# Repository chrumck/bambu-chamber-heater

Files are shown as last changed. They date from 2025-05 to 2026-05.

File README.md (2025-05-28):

# Bambu Lab X1 Chamber Heater Controller

## Description

Code for Bambu Lab X1 Carbon chamber heater controller.
It controls the chamber heater fan, heater core, the chamber light, and the external enclosure fan.
The input are two temperature sensors, the chamber temp sensor and the heater core temp sensor.

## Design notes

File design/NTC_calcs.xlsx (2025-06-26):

Arduino Resolution: | 4.9 | mV | 20.46
Sensors
Vref | 3.3 | V | ATmega32U4
Rref | 4700 | Ohm
Rsensor | 25000 | Ohm
Vout | 2.778 | V
I | 0.11 | mA
I | 0.00011 | A
Rsensor | 25000 | Ohm
 | Rref | Rmin | Rmax | Imin (mA) | Imax (mA) | vmin (V) | vmax (V) | vmin (mV) | vmax (mV) | Pmax (W) | Rmin | Rmax
Temp | 4700 | 120 | 160000 | 0.68 | 0.02 | 0.082 | 3.206 | 82.15767635 | 3205.82878 | 6.612021858e-05 | 4820 | 164700
 | degC | R | I (mA) | I (uA) | U (V)
 | 0 | 327240 | 0.010 | 9.941555703 | 3.253
 | 10 | 199990 | 0.016 | 16.1219405 | 3.224
 | 25 | 100000 | 0.032 | 31.51862464 | 3.152
 | 40 | 53500 | 0.057 | 56.70103093 | 3.034
 | 50 | 35899 | 0.081 | 81.28279022 | 2.918
 | 60 | 25000 | 0.111 | 111.1111111 | 2.778
 | 80 | 12540 | 0.191 | 191.4153132 | 2.400
 | 100 | 6710 | 0.289 | 289.2199825 | 1.941
 | 125 | 3340 | 0.410 | 410.4477612 | 1.371
 | 200 | 582 | 0.625 | 624.7633472 | 0.364

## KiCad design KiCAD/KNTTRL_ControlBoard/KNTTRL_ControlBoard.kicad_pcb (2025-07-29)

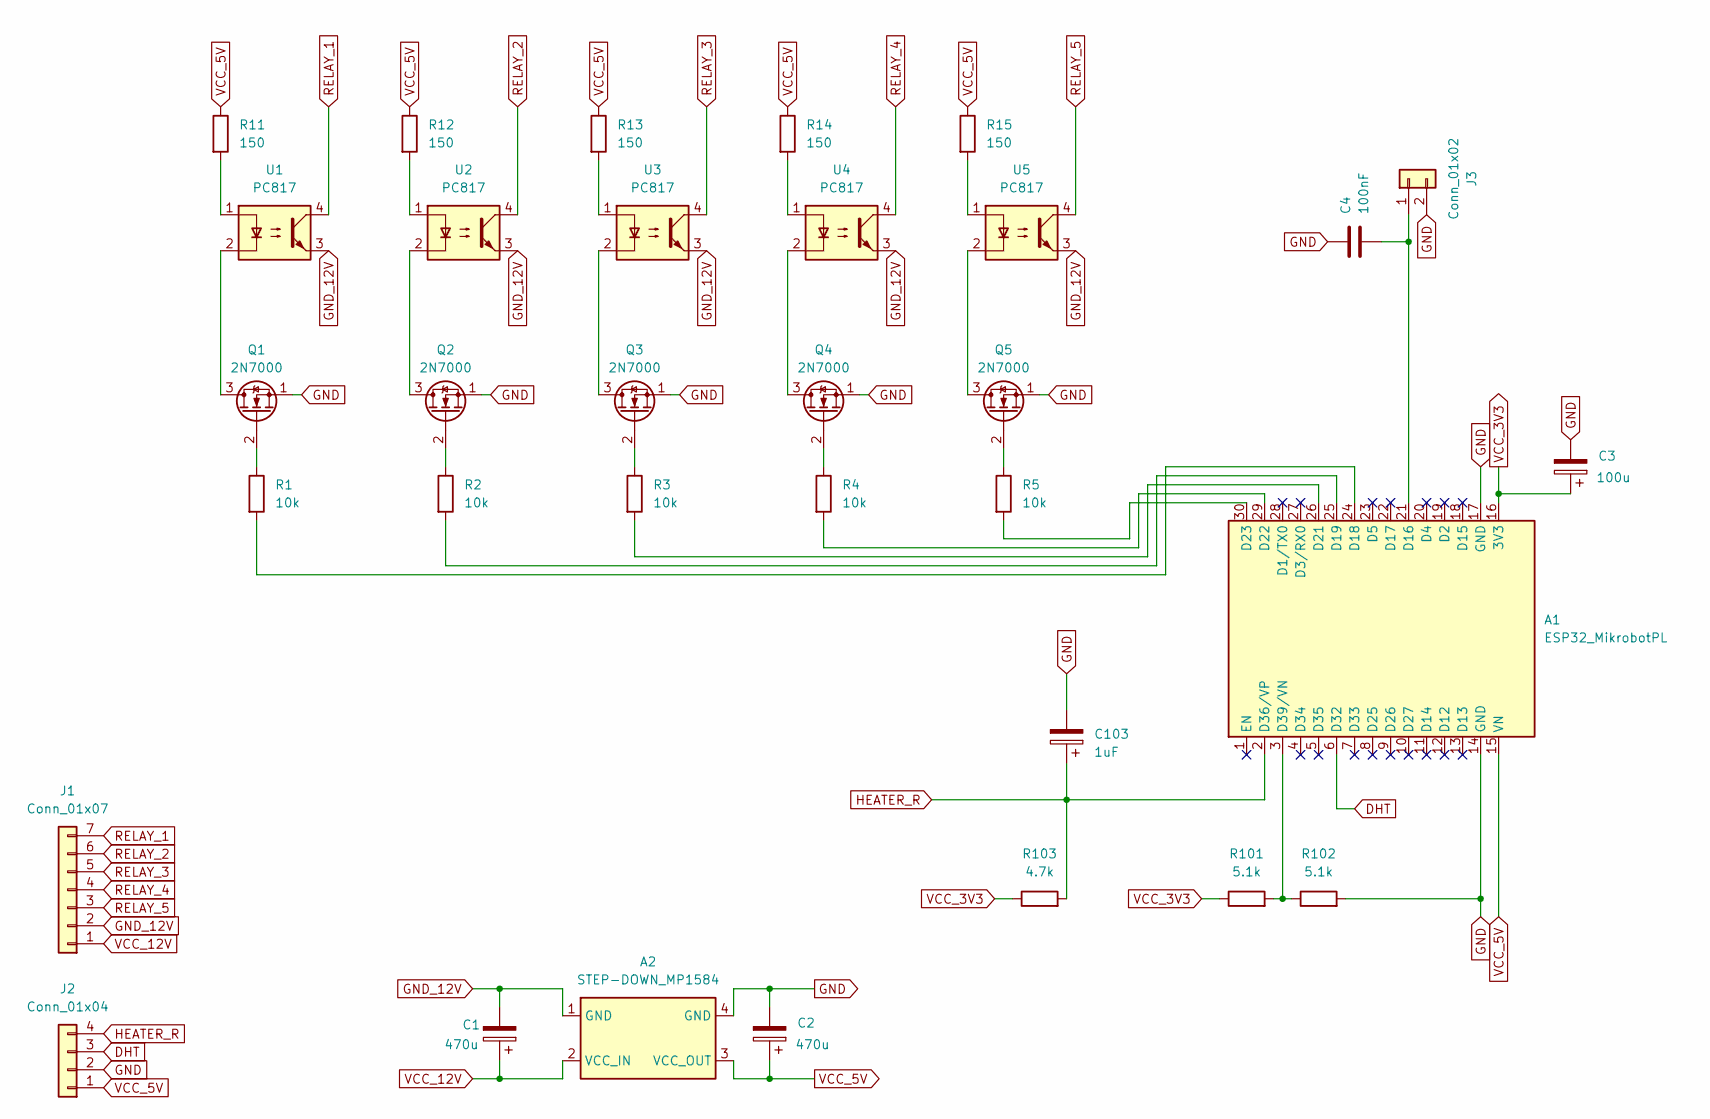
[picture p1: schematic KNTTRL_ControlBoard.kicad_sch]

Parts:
A1: ESP32_MikrobotPL
A2: STEP-DOWN_MP1584
C1, C2: 470u; CP_Radial_D5.0mm_P2.50mm
C3: 100u; CP_Radial_D5.0mm_P2.50mm
C4: 100nF; C_Disc_D5.0mm_W2.5mm_P2.50mm
C103: 1uF; CP_Radial_D5.0mm_P2.50mm
J1: Conn_01x07; PinHeader_1x07_P2.54mm_Vertical
J2: Conn_01x04; PinHeader_1x04_P2.54mm_Vertical
J3: Conn_01x02; PinHeader_1x02_P2.54mm_Vertical
Q1, Q2, Q3, Q4, Q5: 2N7000; TO-92_Inline_Wide
R1, R2, R3, R4, R5: 10k; R_Axial_DIN0207_L6.3mm_D2.5mm_P7.62mm_Horizontal
R11, R12, R13, R14, R15: 150; R_Axial_DIN0309_L9.0mm_D3.2mm_P2.54mm_Vertical
R101, R102: 5.1k; R_Axial_DIN0207_L6.3mm_D2.5mm_P7.62mm_Horizontal
R103: 4.7k; R_Axial_DIN0207_L6.3mm_D2.5mm_P7.62mm_Horizontal
U1, U2, U3, U4, U5: PC817; DIP-4_W7.62mm

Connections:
DHT: A1.6 (D32), J2.3
GND: A1.14 (GND), A1.17 (GND), A2.4 (GND), C2.2, C3.2, C4.1, C103.2, J2.2, J3.2, Q1.1 (S), Q2.1 (S), Q3.1 (S), Q4.1 (S), Q5.1 (S), R102.2
GND_12V: A2.1 (GND), C1.2, J1.2 (GND_12V), U1.3, U2.3, U3.3, U4.3, U5.3
HEATER_R: A1.2 (D36/VP), C103.1, J2.4, R103.2
unnamed: A1.21 (D16), C4.2, J3.1
unnamed: A1.24 (D18), R1.2
unnamed: A1.25 (D19), R2.2
unnamed: A1.26 (D21), R3.2
unnamed: A1.29 (D22), R4.2
unnamed: A1.30 (D23), R5.2
unnamed: A1.3 (D39/VN), R101.2, R102.1
unnamed: Q1.3 (D), U1.2
unnamed: Q1.2 (G), R1.1
unnamed: Q2.3 (D), U2.2
unnamed: Q2.2 (G), R2.1
unnamed: Q3.3 (D), U3.2
unnamed: Q3.2 (G), R3.1
unnamed: Q4.3 (D), U4.2
unnamed: Q4.2 (G), R4.1
unnamed: Q5.3 (D), U5.2
unnamed: Q5.2 (G), R5.1
unnamed: R11.2, U1.1
unnamed: R12.2, U2.1
unnamed: R13.2, U3.1
unnamed: R14.2, U4.1
unnamed: R15.2, U5.1
RELAY_1: J1.7, U1.4
RELAY_2: J1.6, U2.4
RELAY_3: J1.5, U3.4
RELAY_4: J1.4, U4.4
RELAY_5: J1.3, U5.4
VCC_3V3: A1.16 (3V3), C3.1, R101.1, R103.1
VCC_5V: A1.15 (VN), A2.3 (VCC_OUT), C2.1, J2.1, R11.1, R12.1, R13.1, R14.1, R15.1
VCC_12V: A2.2 (VCC_IN), C1.1, J1.1 (VCC_12V)

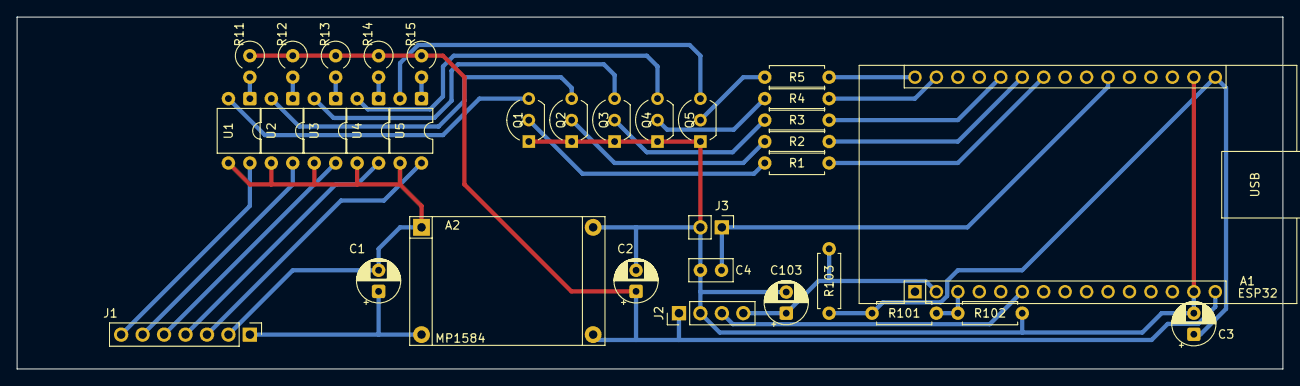
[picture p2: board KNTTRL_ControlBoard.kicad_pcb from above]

Board: 2 copper layers, 149.9 x 41.7 mm, 33 parts (0 on the bottom side), 34 nets.

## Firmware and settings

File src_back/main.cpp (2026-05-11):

#include "./main.hpp"

Preferences prefs;
AsyncWebServer server(80);
AsyncWebSocket ws("/ws");

u32_t lightButtonPressTime = 0;
volatile bool loopRunRequested = false;

// All temperatures in DegC if otherwise not specified
float chamberTemp = TEMP_DEFAULT;
u8_t tempSet = DEFAULT_TEMP_SET;
u8_t dhtFailCount = 0;

float vRef = 0.0;
float heaterV = 0.0;
float heaterR = 0.0;
float heaterLastDutyCycle = 0.0;

// All times are in milliseconds from last boot if otherwise not specified
u32_t operationMaxTime = 0;

bool heaterFanSet = false;
bool doorFanSet = false;
bool auxFanSet = false;

DHTNEW dht(DHT_PIN);

void setup() {
  Serial.setRxBufferSize(SERIAL_BUFFER_SIZE);
  Serial.begin(SERIAL_BAUD_RATE);

  pinMode(LIGHT_PIN, OUTPUT);
  switchRelayOn(LIGHT_PIN);  // Light on by default
  pinMode(AUX_FAN_PIN, OUTPUT);
  switchRelayOff(AUX_FAN_PIN);
  pinMode(DOOR_FAN_PIN, OUTPUT);
  switchRelayOff(DOOR_FAN_PIN);
  pinMode(HEATER_FAN_PIN, OUTPUT);
  switchRelayOff(HEATER_FAN_PIN);
  pinMode(HEATER_PIN, OUTPUT);
  switchRelayOff(HEATER_PIN);

  pinMode(LIGHT_BUTTON_PIN, INPUT_PULLUP);

  dht.reset();

  prefs.begin(PREFS_NAMESPACE, false);
  String ssid = prefs.getString(PREFS_KEY_WIFI_SSID);
  String pass = prefs.getString(PREFS_KEY_WIFI_PASS);
  prefs.end();

  if (ssid.isEmpty() || pass.isEmpty()) {
    Serial.println("Wifi credentials not available, skipping setting up web server");
    return;
  }

  initWifi(ssid, pass);
  initWebSocket();
  if (!LittleFS.begin(true)) Serial.println("An error has occurred while mounting LittleFS");

  server.on("/", HTTP_GET, [](AsyncWebServerRequest* request) {
    AsyncWebServerResponse* response = request->beginResponse(LittleFS, "/index.html.gz", "text/html");
    response->addHeader("Content-Encoding", "gzip");
    request->send(response);
    });

  server.begin();
}

void loop() {
  handleLightButtonPress();

  receiveSerial();

  static u32_t lastCycleTime = 0;

  u32_t currentTime = millis();
  if (!loopRunRequested && currentTime - lastCycleTime < LOOP_INTERVAL_MS) return;

  loopRunRequested = false;
  lastCycleTime = currentTime;

  readChamberTemp();
  readHeaterR();

  controlHeater();
  controlHeaterFan();
  controlAuxFan();
  controlDoorFan();

  notifyWsClients();
  ws.cleanupClients();
}

void handleLightButtonPress() {
  u32_t currentTime = millis();
  if (currentTime - lightButtonPressTime < LIGHT_BUTTON_DEBOUNCE_MS) return;
  if (digitalRead(LIGHT_BUTTON_PIN) != LOW) return;

  switchRelay(LIGHT_PIN, !isRelayOn(LIGHT_PIN));
  loopRunRequested = true;
  lightButtonPressTime = currentTime;
}

void initWifi(String ssid, String pass) {
  WiFi.mode(WIFI_STA);
  WiFi.begin(ssid, pass);

  Serial.print("Connecting to WiFi, ssid: ");
  Serial.print(ssid);
  Serial.print(", pass: ");
  Serial.print(pass);

  auto retries = 0;
  while (WiFi.status() != WL_CONNECTED) {
    Serial.print('.');
    delay(1000);
    if (retries++ >= WIFI_RETRY_COUNT) {
      Serial.println("Failed to connect to WiFi");
      return;
    }
  }

  Serial.print("WiFi connected, IP: ");
  Serial.println(WiFi.localIP());
}

void initWebSocket() {
  if (WiFi.status() != WL_CONNECTED) {
    Serial.println("WiFi not connected, skipping web socket setup");
    return;
  }

  Serial.println("Initializing web socket");
  ws.onEvent(wsOnEvent);
  server.addHandler(&ws);
}

void wsOnEvent(AsyncWebSocket* server, AsyncWebSocketClient* client, AwsEventType type, void* arg, uint8_t* data, size_t len) {
  switch (type) {
  case WS_EVT_CONNECT:
  case WS_EVT_DISCONNECT:
    loopRunRequested = true;
    break;
  case WS_EVT_DATA:
    handleWebSocketMessage(arg, data, len);
    break;
  case WS_EVT_PONG:
  case WS_EVT_ERROR:
    break;
  }
}

void handleWebSocketMessage(void* arg, uint8_t* data, size_t length) {
  AwsFrameInfo* info = (AwsFrameInfo*)arg;
  if (!info->final || info->index != 0 || info->len != length || info->opcode != WS_BINARY) return;

  if (length != 2 && (data[0] == WsRequest_SetHeaterTimeLeft && length != 3)) { return; }

  switch (data[0]) {
  case WsRequest_SetTemp: {
    tempSet = data[1];
    break;
  }
  case WsRequest_SetHeaterTimeLeft: {
    u16_t timeLeftMins = data[1] | (data[2] << 8);
    operationMaxTime = millis() + timeLeftMins * 60000 + SET_TIME_EXTRA_MS;
    break;
  }
  case WsRequest_SetLight: {
    bool lightOn = data[1] == 1;
    switchRelay(LIGHT_PIN, lightOn);
    break;
  }
  case WsRequest_SetHeaterFan: {
    heaterFanSet = data[1] == 1;
    break;
  }
  case WsRequest_SetDoorFan: {
    doorFanSet = data[1] == 1;
    break;
  }
  case WsRequest_SetAuxFan: {
    auxFanSet = data[1] == 1;
    break;
  }
  }

  loopRunRequested = true;
}

void receiveSerial() {
  static char serialBuf[SERIAL_BUFFER_SIZE];

  if (Serial.available() == 0) return;

  int idx = 0;
  memset(&serialBuf, 0, SERIAL_BUFFER_SIZE);
  while (Serial.available() > 0 && idx < SERIAL_BUFFER_SIZE) {
    char currentChar = Serial.read();
    if (currentChar == STRING_END_MARKER) break;
    serialBuf[idx++] = currentChar;
  }

  String message = String(serialBuf);

  if (message.startsWith("ssid ")) {
    savePrefs(PREFS_KEY_WIFI_SSID, message.substring(5));
    return;
  }

  if (message.startsWith("pass ")) {
    savePrefs(PREFS_KEY_WIFI_PASS, message.substring(5));
    return;
  }

  if (message.equals("reset_reason")) {
    Serial.printf("Reset reason: %d \n", esp_reset_reason());
    return;
  }

  Serial.println("Command not recognized");
}

void savePrefs(const char* prefsKey, String prefsValue) {
  prefs.begin(PREFS_NAMESPACE, false);
  prefs.putString(prefsKey, prefsValue);
  prefs.end();

  Serial.printf("Saved key: %s, value: %s \n", prefsKey, prefsValue.c_str());
  Serial.println("You need to reboot for changes to take effect");
}

void readChamberTemp() {
  int chamberTempReadResult = dht.read();

  if (chamberTempReadResult == DHTLIB_WAITING_FOR_READ) { return; }

  if (chamberTempReadResult == DHTLIB_OK) {
    dhtFailCount = 0;
    chamberTemp = dht.getTemperature();
    return;
  }

  Serial.printf("Failed chamber temp read, result: %d \n", chamberTempReadResult);

  dhtFailCount++;

  if (dhtFailCount >= DHT_MAX_FAIL_COUNT) {
    Serial.println("Too many failed chamber temp reads, setting temp value to invalid");
    chamberTemp = TEMP_ERROR_VALUE;
    setHeater(false);
  }
}

void readHeaterR() {
  vRef = REF_V_DEFAULT;
  heaterV = 0;
  heaterR = 0;

  u16_t adcFailCount = 0;
  float vRefSum = 0;
  float heaterVSum = 0;

  for (int i = 0; i < ANALOG_READ_COUNT; i++) {
    float currentVRef = readAdcMilliVolts(REF_V_PIN) * REF_V_ADC_RATIO / 1000.0;
    if (currentVRef >= REF_V_MIN && currentVRef <= REF_V_MAX) {
      vRefSum += currentVRef;
    }
    else {
      adcFailCount++;
      vRefSum += REF_V_DEFAULT;
    }

    float currentHeaterV = readAdcMilliVolts(HEATER_R_PIN) / 1000.0;
    if (currentHeaterV >= HEATER_V_MIN && currentHeaterV <= HEATER_V_MAX) {
      heaterVSum += currentHeaterV;
    }
    else {
      adcFailCount++;
      heaterVSum += HEATER_V_DEFAULT;
    }

    if (adcFailCount >= ADC_MAX_FAIL_COUNT) {
      Serial.println("Too many ADC read failures, setting ADC data to 0");
      vRef = 0.0;
      heaterV = 0.0;
      heaterR = 0.0;
      setHeater(false);
      return;
    }
  }

  vRef = vRefSum / ANALOG_READ_COUNT;
  heaterV = heaterVSum / ANALOG_READ_COUNT;
  heaterR = heaterV * REF_R / (vRef - heaterV);

  if (heaterR > HEATER_R_MAX || heaterR < HEATER_R_MIN) {
    Serial.printf("Heater R out of bounds: %.0f \n", heaterR);
    heaterR = 0;
    setHeater(false);
  }
}

void controlHeater() {
  bool heaterOn = isRelayOn(HEATER_PIN);
  if (heaterOn && (heaterR == 0 || chamberTemp == TEMP_ERROR_VALUE)) {
    Serial.println("Switching heater OFF, invalid heaterR or chamberTemp");
    setHeater(false);
    return;
  }

  if (heaterOn && (heaterR < HEATER_R_OFF || chamberTemp > tempSet)) {
    setHeater(false);
    return;
  }

  u32_t currentTime = millis();
  u32_t timeLeftToRunMs = currentTime > operationMaxTime ? 0 : operationMaxTime - currentTime;

  if (heaterOn && timeLeftToRunMs == 0) {
    Serial.println("Max heater time reached");
    setHeater(false);
    return;
  }

  if (!heaterOn &&
    timeLeftToRunMs > 0 &&
    heaterR > HEATER_R_ON &&
    chamberTemp < (tempSet - CHAMBER_TEMP_ON_DEADBAND)
    ) {
    setHeater(true);
  }
}

void setHeater(bool on) {
  static u32_t heaterLastTimeOn = 0;
  static u32_t heaterLastTimeOff = 0;

  bool heaterOn = isRelayOn(HEATER_PIN);
  if (heaterOn == on) { return; }

  u32_t currentTime = millis();

  if (on) {
    Serial.println("Switching heater ON");
    switchRelayOn(HEATER_PIN);
    heaterLastTimeOn = currentTime;
    return;
  }

  Serial.println("Switching heater OFF");
  switchRelayOff(HEATER_PIN);

  if (heaterLastTimeOff > 0 && heaterLastTimeOn > 0) {
    u32_t lastOffCycle = heaterLastTimeOn - heaterLastTimeOff;
    u32_t lastOnCycle = currentTime - heaterLastTimeOn;
    heaterLastDutyCycle = (float)lastOnCycle / (lastOffCycle + lastOnCycle);
    Serial.printf("Last duty cycle: %f \n", heaterLastDutyCycle);
  }

  heaterLastTimeOff = currentTime;
}

void controlHeaterFan() {
  bool fanOn = isRelayOn(HEATER_FAN_PIN);
  bool heaterOn = isRelayOn(HEATER_PIN);

  if (heaterR == 0 || heaterOn || heaterFanSet) {
    if (fanOn) return;
    Serial.println("Switching heater fan ON");
    switchRelayOn(HEATER_FAN_PIN);
    return;
  }

  if (!fanOn && heaterR < HEATER_R_FAN_ON) {
    Serial.println("HeaterR low, switching heater fan ON");
    switchRelayOn(HEATER_FAN_PIN);
    return;
  }

  if (fanOn && heaterR > HEATER_R_FAN_ON + HEATER_R_DEADBAND) {
    Serial.println("HeaterR high, switching heater fan OFF");
    switchRelayOff(HEATER_FAN_PIN);
    return;
  }
}

void controlAuxFan() {
  bool fanOn = isRelayOn(AUX_FAN_PIN);

  if (auxFanSet || chamberTemp == TEMP_ERROR_VALUE) {
    if (fanOn) return;
    Serial.println("Switching aux fan ON");
    switchRelayOn(AUX_FAN_PIN);
    return;
  }

  u32_t currentTime = millis();
  u32_t timeLeftToRunMs = currentTime > operationMaxTime ? 0 : operationMaxTime - currentTime;
  if (timeLeftToRunMs == 0) {
    if (!fanOn) return;
    Serial.println("Max time reached, switching aux fan off");
    switchRelayOff(AUX_FAN_PIN);
    return;
  }

  float auxFanTemp = chamberTemp - AUX_FAN_ON_TEMP;
  if (!fanOn && auxFanTemp > tempSet) {
    Serial.println("Chamber temp too high, switching aux fan ON");
    switchRelayOn(AUX_FAN_PIN);
    return;
  }

  if (fanOn&& auxFanTemp < tempSet - CHAMBER_TEMP_ON_DEADBAND) {
    Serial.println("Chamber temp low enough, switching aux fan OFF");
    switchRelayOff(AUX_FAN_PIN);
    return;
  }
}

void controlDoorFan() {
  bool fanOn = isRelayOn(DOOR_FAN_PIN);
  bool auxFanOn = isRelayOn(AUX_FAN_PIN);

  if (doorFanSet || auxFanOn || chamberTemp == TEMP_ERROR_VALUE) {
    if (fanOn) return;
    Serial.println("Switching door fan ON");
    switchRelayOn(DOOR_FAN_PIN);
    return;
  }

  u32_t currentTime = millis();
  u32_t timeLeftToRunMs = currentTime > operationMaxTime ? 0 : operationMaxTime - currentTime;
  if (timeLeftToRunMs == 0) {
    if (!fanOn) return;
    Serial.println("Max time reached, switching door fan off");
    switchRelayOff(DOOR_FAN_PIN);
    return;
  }

  float doorFanTemp = chamberTemp - DOOR_FAN_ON_TEMP;
  if (!fanOn && doorFanTemp > tempSet) {
    Serial.println("Chamber temp high, switching door fan ON");
    switchRelayOn(DOOR_FAN_PIN);
    return;
  }

  if (fanOn && doorFanTemp < tempSet - CHAMBER_TEMP_ON_DEADBAND) {
    Serial.println("Chamber temp low, switching door fan OFF");
    switchRelayOff(DOOR_FAN_PIN);
    return;
  }
}

void notifyWsClients() {
  static u8_t wsMessage[WS_MESSAGE_LENGTH];
  memset(&wsMessage, 0, WS_MESSAGE_LENGTH);

  u16_t tempBytes = (u16_t)((chamberTemp + WS_MESSAGE_TEMP_OFFSET) * WS_MESSAGE_TEMP_FACTOR);
  wsMessage[Byte_Temp_1] = tempBytes & 0xFF;
  wsMessage[Byte_Temp_2] = (tempBytes >> 8) & 0xFF;
  wsMessage[Byte_TempSet] = tempSet;

  u32_t currentTime = millis();
  u32_t heaterTimeLeftSeconds = operationMaxTime > currentTime ? (operationMaxTime - currentTime) / 1000 : 0;
  u16_t heaterTimeLeftMins = heaterTimeLeftSeconds / 60;
  wsMessage[Byte_HeaterOnTimeLeftMins1] = heaterTimeLeftMins & 0xFF;
  wsMessage[Byte_HeaterOnTimeLeftMins2] = (heaterTimeLeftMins >> 8) & 0xFF;

  u16_t heaterRBytes = heaterR > 0xFFFF ? 0xFFFF : (u16_t)heaterR;
  wsMessage[Byte_HeaterR_1] = heaterRBytes & 0xFF;
  wsMessage[Byte_HeaterR_2] = (heaterRBytes >> 8) & 0xFF;

  wsMessage[Byte_HeaterDutyCycle] = (u8_t)(heaterLastDutyCycle * 255);

  bool heaterOn = isRelayOn(HEATER_PIN);
  bool lightOn = isRelayOn(LIGHT_PIN);
  bool heaterFanOn = isRelayOn(HEATER_FAN_PIN);
  bool doorFanOn = isRelayOn(DOOR_FAN_PIN);
  bool auxFanOn = isRelayOn(AUX_FAN_PIN);

  wsMessage[Byte_Flags] |=
    (heaterOn << Flag_HeaterOn) |
    (lightOn << Flag_LightOn) |
    (heaterFanSet << Flag_HeaterFanSet) |
    (heaterFanOn << Flag_HeaterFanOn) |
    (doorFanSet << Flag_DoorVentFanSet) |
    (doorFanOn << Flag_DoorVentFanOn) |
    (auxFanSet << Flag_AuxFanSet) |
    (auxFanOn << Flag_AuxFanOn);

  ws.binaryAll(wsMessage, WS_MESSAGE_LENGTH);

  Serial.printf(
    "Temp: %.2f, Set:%d, TimeLeftSec:%d, vRef:%.4f, heaterV:%.4f, heaterR:%d, DutyCycle:%.2f, heaterOn:%d, lightOn: %d, heaterFanSet:%d, heaterFanOn:%d, doorFanSet:%d, doorFanOn:%d, auxFanSet:%d, auxFanOn:%d \n",
    chamberTemp, tempSet, heaterTimeLeftSeconds, vRef, heaterV, (u32_t)heaterR, heaterLastDutyCycle, heaterOn, lightOn, heaterFanSet, heaterFanOn, doorFanSet, doorFanOn, auxFanSet, auxFanOn);
}

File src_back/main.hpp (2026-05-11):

#include <Arduino.h>
#include <WiFi.h>
#include <AsyncTCP.h>
#include <ESPAsyncWebServer.h>
#include <Preferences.h>
#include "LittleFS.h"
#include <dhtnew.h>

#define SERIAL_BAUD_RATE 115200
#define SERIAL_BUFFER_SIZE 256
#define STRING_END_MARKER '\n'

#define PREFS_NAMESPACE "KnurToryTroller"
#define PREFS_KEY_WIFI_SSID "wifiSsid"
#define PREFS_KEY_WIFI_PASS "wifiPass"

#define WIFI_RETRY_COUNT 60
#define LOOP_INTERVAL_MS 2500

#define SET_TIME_EXTRA_MS 3000

#define LIGHT_BUTTON_PIN 16
#define LIGHT_BUTTON_DEBOUNCE_MS 1000

#define LIGHT_PIN 18
#define HEATER_FAN_PIN 19
#define AUX_FAN_PIN 21
#define DOOR_FAN_PIN 23
#define HEATER_PIN 22

#define DHT_PIN 32
#define HEATER_R_PIN 36
#define REF_V_PIN 39

#define DHT_MAX_FAIL_COUNT 5
#define TEMP_DEFAULT 30.0
#define TEMP_ERROR_VALUE (-WS_MESSAGE_TEMP_OFFSET)

#define ANALOG_READ_COUNT 100
#define ANALOG_READ_NUM 980
#define ANALOG_READ_DEN 1000
#define ANALOG_READ_OFFSET (-20)
#define ADC_MAX_FAIL_COUNT 3

#define readAdcMilliVolts(_pin) \
   (((int32_t)analogReadMilliVolts(_pin) * ANALOG_READ_NUM / ANALOG_READ_DEN) + ANALOG_READ_OFFSET)

#define isRelayOn(_pin) (digitalRead(_pin) == HIGH)
#define switchRelay(_pin, _on) digitalWrite(_pin, _on ? HIGH : LOW)
#define switchRelayOn(_pin) switchRelay(_pin, true)
#define switchRelayOff(_pin) switchRelay(_pin, false)

#define REF_R 4730
#define REF_V_DEFAULT 3.25
#define REF_V_MIN 3.0
#define REF_V_MAX 3.5
#define REF_V_ADC_RATIO 2.0

#define HEATER_V_MIN 0.05
#define HEATER_V_MAX 3.10
#define HEATER_V_DEFAULT 1.941 // corresponds to ~100 degC @ vRef = 3.3V
#define HEATER_R_MAX 200000
#define HEATER_R_MIN 120
#define HEATER_R_FAN_ON 20900 // 65 degC
#define HEATER_R_DEADBAND 5000
#define HEATER_R_ON 4410  // 115 degC
#define HEATER_R_OFF 3340  // 125 degC

// #define HEATER_R_ON 7784 // 95 degC
// #define HEATER_R_ON 5070 // 110 degC
// #define HEATER_R_OFF 5070 // 110 degC
// #define HEATER_R_OFF 3850 // 120 degC

#define DEFAULT_TEMP_SET 60
#define CHAMBER_TEMP_ON_DEADBAND 0.2
#define AUX_FAN_ON_TEMP 2.0
#define DOOR_FAN_ON_TEMP 1.2

#define WS_MESSAGE_LENGTH 9
#define WS_MESSAGE_TEMP_FACTOR 100
#define WS_MESSAGE_TEMP_OFFSET 50

enum WsMessageBytes {
  Byte_Temp_1 = 0,
  Byte_Temp_2 = 1,
  Byte_TempSet = 2,
  Byte_HeaterOnTimeLeftMins1 = 3,
  Byte_HeaterOnTimeLeftMins2 = 4,
  Byte_HeaterR_1 = 5,
  Byte_HeaterR_2 = 6,
  Byte_HeaterDutyCycle = 7,
  Byte_Flags = 8,
};

enum WsMessageFlags {
  Flag_HeaterOn = 0,
  Flag_LightOn = 1,
  Flag_HeaterFanSet = 2,
  Flag_HeaterFanOn = 3,
  Flag_DoorVentFanSet = 4,
  Flag_DoorVentFanOn = 5,
  Flag_AuxFanSet = 6,
  Flag_AuxFanOn = 7,
};

enum WsRequestCode {
  WsRequest_SetTemp = 0xa1,
  WsRequest_SetHeaterTimeLeft = 0xa2,
  WsRequest_SetLight = 0xa3,
  WsRequest_SetHeaterFan = 0xa4,
  WsRequest_SetDoorFan = 0xa5,
  WsRequest_SetAuxFan = 0xa6,
};

void IRAM_ATTR handleLightButtonPress();
void initWifi(String ssid, String pass);
void initWebSocket();
void wsOnEvent(AsyncWebSocket* server, AsyncWebSocketClient* client, AwsEventType type, void* arg, uint8_t* data, size_t len);
void handleWebSocketMessage(void* arg, uint8_t* data, size_t len);
void receiveSerial();
void savePrefs(const char* prefsKey, String prefsValue);
void readChamberTemp();
void readHeaterR();
void setHeater(bool on);
void controlHeater();
void controlHeaterFan();
void controlAuxFan();
void controlDoorFan();
void notifyWsClients();

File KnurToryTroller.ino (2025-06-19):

#include <Preferences.h>
#include <dhtnew.h>

#define SERIAL_BAUD_RATE 115200
#define SERIAL_BUFFER_SIZE 256
#define LOOP_INTERVAL_MS 2500
#define MAX_HEATER_TIME_MS 3600e3

#define DHT_PIN 34
#define DHT_MAX_FAIL_COUNT 5

#define ANALOG_READ_CONVERSION_FACTOR 0.0048828125

#define ANALOG_READ_COUNT 100
#define REF_VOLTAGE_PIN 23
#define HEATER_TEMP_PIN 35
#define HEATER_TEMP_REF_R 4700
#define HEATER_TEMP_REF_V_MIN 4.8
#define HEATER_TEMP_REF_V_MAX 5.2

#define HEATER_TEMP_R_MAX 200000
#define HEATER_TEMP_R_MIN 120
// #define HEATER_TEMP_R_ON 7784 // 95 degC
// #define HEATER_TEMP_R_ON 5070 // 110 degC
#define HEATER_TEMP_R_ON 4410 // 115 degC
// #define HEATER_TEMP_R_OFF 5070 // 110 degC
// #define HEATER_TEMP_R_OFF 3850 // 120 degC
#define HEATER_TEMP_R_OFF 3340 // 125 degC

#define DEFAULT_CHAMBER_TEMP_OFF 60.0
#define CHAMBER_TEMP_ON_DEADBAND 0.3

#define HEATER_RELAY_PIN 32

#define switchHeaterOff()\
    if (isHeaterOn) {\
        digitalWrite(HEATER_RELAY_PIN, HIGH);\
        lastTimeOff = currentTime;\
    }\

Preferences preferences;

u32_t maxHeaterTimeMs = MAX_HEATER_TIME_MS;
float chamberTempOff = DEFAULT_CHAMBER_TEMP_OFF;
u32_t lastCycleTime = millis();
int dhtReadFailCount = 0;
float chamberTempDegC = 0.0;

u32_t lastTimeOn = 0;
u32_t lastTimeOff = 0;

DHTNEW dht(DHT_PIN);

void setup() {
    Serial.begin(SERIAL_BAUD_RATE);

    pinMode(HEATER_RELAY_PIN, OUTPUT);
    digitalWrite(HEATER_RELAY_PIN, HIGH);

    dht.reset();
}

void loop() {
    receiveSerial();

    u32_t currentTime = millis();
    if (currentTime - lastCycleTime < LOOP_INTERVAL_MS) return;
    lastCycleTime = currentTime;

    bool isHeaterOn = digitalRead(HEATER_RELAY_PIN) == LOW;
    Serial.print(isHeaterOn ? "Heater is ON" : "Heater is OFF");

    int chamberTempReadResult = dht.read();
    if (chamberTempReadResult != DHTLIB_OK) {
        Serial.print("; Failed chamber temp read, result: ");
        Serial.print(chamberTempReadResult);

        dhtReadFailCount++;

        if (dhtReadFailCount >= DHT_MAX_FAIL_COUNT) {
            Serial.println("Too many failed chamber temp reads");
            switchHeaterOff();
            return;
        }
    }
    else {
        dhtReadFailCount = 0;
        chamberTempDegC = dht.getTemperature();
    }

    Serial.print("; chamber degC: ");
    Serial.print(chamberTempDegC);

    float vRefAvg = 0;
    float heaterTempR = 0;
    for (int i = 0; i < ANALOG_READ_COUNT; i++)
    {
        float vRef = (analogRead(REF_VOLTAGE_PIN) * ANALOG_READ_CONVERSION_FACTOR * 2);
        vRefAvg += vRef;

        if (vRef < HEATER_TEMP_REF_V_MIN || vRef > HEATER_TEMP_REF_V_MAX) {
            Serial.println();
            Serial.print("Reference voltage out of bounds: ");
            Serial.println(vRef);
            switchHeaterOff();
            return;
        }

        float heaterTempVoltage = (analogRead(HEATER_TEMP_PIN) * ANALOG_READ_CONVERSION_FACTOR);
        heaterTempR += heaterTempVoltage * HEATER_TEMP_REF_R / (vRef - heaterTempVoltage);
    }

    vRefAvg /= ANALOG_READ_COUNT;
    heaterTempR /= ANALOG_READ_COUNT;

    if (heaterTempR > HEATER_TEMP_R_MAX || heaterTempR < HEATER_TEMP_R_MIN) {
        Serial.println();
        Serial.print("Heater temperature resistance out of bounds: ");
        Serial.println(heaterTempR);
        switchHeaterOff();
        return;
    }

    Serial.print("; vRef: ");
    Serial.print(vRefAvg);

    Serial.print("; heater R: ");
    Serial.print(heaterTempR);

    u32_t timeLeftToRunMs = currentTime > maxHeaterTimeMs ? 0 : maxHeaterTimeMs - currentTime;
    Serial.print("; time left mins: ");
    Serial.print(timeLeftToRunMs / 60000);

    if (timeLeftToRunMs == 0) {
        if (isHeaterOn) {
            Serial.println("; Max heater time reached, stopping heater");
            switchHeaterOff();
        }
        else {
            Serial.println("; Max heater time reached, heater off");
        }

        return;
    }
    else {
        Serial.println();
    }

    if (isHeaterOn && (heaterTempR < HEATER_TEMP_R_OFF || chamberTempDegC > chamberTempOff)) {
        Serial.println("Switching heater OFF");
        switchHeaterOff();
        return;
    }

    if (!isHeaterOn && heaterTempR > HEATER_TEMP_R_ON && chamberTempDegC < (chamberTempOff - CHAMBER_TEMP_ON_DEADBAND)) {

        if (lastTimeOff > 0 && lastTimeOn > 0) {
            u32_t lastOffCycle = currentTime - lastTimeOff;
            u32_t lastOnCycle = lastTimeOff - lastTimeOn;
            float dutyCycle = (float)lastOnCycle / (lastOffCycle + lastOnCycle);
            Serial.print("Last duty cycle:");
            Serial.println(dutyCycle);
        }

        Serial.println("Switching heater ON");
        digitalWrite(HEATER_RELAY_PIN, LOW);
        lastTimeOn = currentTime;
    }
}

void receiveSerial() {
    static const char endMarker = '\n';
    static char serialBuf[SERIAL_BUFFER_SIZE];
    static byte ndx;
    static char rc;

    if (Serial.available() == 0) return;

    ndx = 0;
    memset(&serialBuf, 0, SERIAL_BUFFER_SIZE);
    while (Serial.available() > 0 && ndx < SERIAL_BUFFER_SIZE) {
        rc = Serial.read();
        if (rc == endMarker) break;
        serialBuf[ndx++] = rc;
    }

    String message = String(serialBuf);

    if (message.length() != 4 && message.length() < 6) {
        Serial.println("Invalid request");
        return;
    }

    if (message.equals("time")) {
        Serial.print("heater time left in minutes: ");
        Serial.println((int)((maxHeaterTimeMs - millis()) / 60e3));
    }

    if (message.startsWith("time ")) {
        u32_t requestedTimeMs = (u32_t)message.substring(5).toInt() * 60e3;
        maxHeaterTimeMs = requestedTimeMs + millis();
        Serial.print("new max heater time in minutes: ");
        Serial.println((int)(requestedTimeMs / 60e3));
    }

    if (message.equals("temp")) {
        Serial.print("chamber temp set: ");
        Serial.println(chamberTempOff);
    }

    if (message.startsWith("temp ")) {
        chamberTempOff = message.substring(5).toInt();
        Serial.print("new chamber max temp:");
        Serial.println(chamberTempOff);
    }
}

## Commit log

2024-02-15 Add max time of 12 hours, shorten loop to 2.5s, allow for 1 dht fail without switching the heater off
2024-02-16 lower heater temps to max 140 degC
2024-02-16 tweak heater on/off temps; print vref
2024-02-20 move files to 'design' folder
    [NTC_calcs.xlsx]
2024-02-20 bump heater core temps to 110/95; add duty cycle
2024-02-21 tweak temperatures
2024-06-28 bump heater temp to 125 degC; tweak serial reporting
2025-05-28 convert to ESP32, set up arduino IDE
2025-06-02 use attachments for icon and manifest
2025-06-12 fix web socket url
2025-06-15 add switches
2025-06-16 move switch to a component; add header 3d printer icon
2025-06-19 refactor ino for compiling on esp32
2025-06-19 rename ino back, Arduino IDE complaining
2025-06-20 first round of refactoring ino for websocket and more relays
2025-06-21 add println where necessary
2025-06-21 remove arduino extension; prep for platformio
2025-06-21 try move arduino code to main.cpp
2025-06-21 move code out of bambu-chamber-heater.ino
2025-06-21 fix pin assignment and serial baud rate
    [main.cpp, main.hpp]
2025-06-21 Wire up websocket messages to page state
2025-06-21 wire up ws requests
2025-06-21 rewrite socket error handling
2025-06-22 switch to using analogReadMillivolts
2025-06-22 calibrate ADC
2025-06-22 fix relay control for n-mos drivers
    [main.cpp, main.hpp]
2025-06-22 change heater V to 3.3V
2025-06-22 update design files
    [NTC_calcs.xlsx]
2025-06-23 Add handling of light button press
2025-06-23 Finish deploying html to esp32
2025-06-23 shuffle pin assignments
2025-06-24 add door fan on on temp 1 deg above set
2025-06-26 update pin assignments
2025-06-26 refactor ADC reading logic
    [NTC_calcs.xlsx]
2025-06-26 reassign light button
2025-06-26 fix door and aux fan logic
    [main.cpp]
2025-06-26 fix heater logic. other tweaks
    [main.cpp, main.hpp]
2025-06-26 remove calls to serial in interrupts, possibly clashing with main code trying to print to serial at the same time
2025-06-28 remove switch interrupt handler, replace with polling
    [main.cpp]
2025-06-28 add reset_reason to serial commands
    [main.cpp]
2025-07-13 Add KiCAD design for KNTTRL_ControlBoard
    [KNTTRL_ControlBoard.kicad_pcb, KNTTRL_ControlBoard.kicad_sch]
2025-07-13 minor tweaks to ADC constants
2025-07-20 update gitignore for KiCad lock files
2025-07-20 assign pins 18~23 to as relay output
2025-07-29 fix pin assignments
2025-07-29 update KiCAD files
    [KNTTRL_ControlBoard.kicad_pcb, KNTTRL_ControlBoard.kicad_sch]
2025-07-29 decrease adc max fails to 3
    [main.hpp]
2025-08-01 update code to switch off chamber cooling after time elapses
2025-08-25 increase door fan hysteresis
